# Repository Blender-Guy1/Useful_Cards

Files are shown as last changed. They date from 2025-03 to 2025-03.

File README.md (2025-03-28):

# Useful_Cards
This is a repository that contains cards that are useful or fun. This includes business cards that can play Pong and cards that act as simple electronics equipment for troubleshooting on the road.

## The Different Cards

### Business Card that Plays [Pong](https://en.wikipedia.org/wiki/Pong)
This went through 3 iterations before I got one that work, and 5 before I felt comfortable showing this to other people. It is a business card PCB that runs on a button cell battery and can play a any games that will run on the microcontroller. All of which is controlled with an [STM32L010F4](https://www.digikey.com/en/products/detail/stmicroelectronics/STM32L010F4P6/10063389) (which isn't exactly necessary for this application as I am running it like any other STM32 microcontroller.). More information can be found in the readme.md in the folder named "Business Card".

<p align="center">
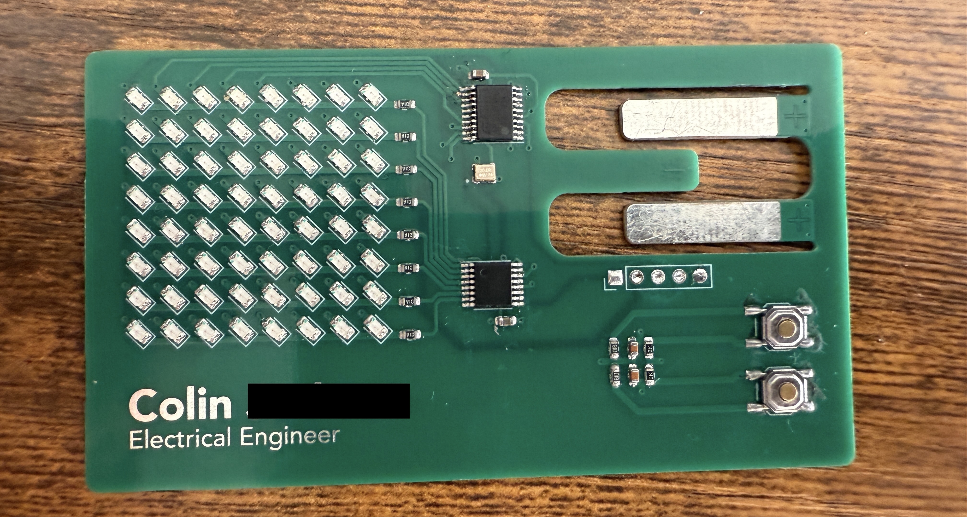
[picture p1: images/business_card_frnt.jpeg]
A picture of a green business card sized PCB that has an 8x8 display along with 2 buttons and 2 integrated circuits.
  
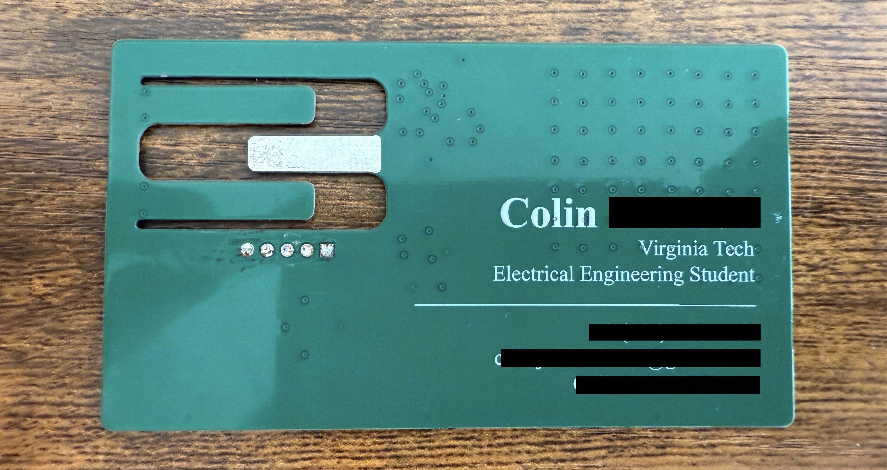
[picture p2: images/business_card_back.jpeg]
The back of the business card has text that is blurred, but it is clear it is a person's business card.
  
</p>

### Why I wanted to make Business Cards

I exhibitted at [OpenSauce 2024](https://opensauce.com/) and had the pleasure to meet [Ben Eater](https://www.youtube.com/@BenEater). He handed me a business card that was a puzzle. When a CR2025 battery was inserted, the 8 LEDs on the PCB would blink "SHAKE ME" in ASCII. Once shaken, the card wrote Ben Eater in the air. This was by far the coolest electronics idea I had ever seen. This got me thinking for a while and eventually I decided to steal his idea and make a 3D holographic business card. But that would be pretty lazy and unoriginal, so I decided on something similar that was simple. This led me to creating a business card that could play pong.

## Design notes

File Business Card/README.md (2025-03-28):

# Business Card that Plays Pong
I wanted a business card that stood out. This went through 3 iterations before I got one that work, and 5 before I felt comfortable showing this to other people. It is a business card PCB that runs on a CR2032/2025 battery and utilizes a shift register to multiplex an 8x8 LED array. All of which is controlled with an STM32L010F4 (which isn't exactly necessary for this application as I am running it like any other STM32 microcontroller.).

<p align="center">
  A picture of a green business card sized PCB that has an 8x8 display along with 2 buttons and 2 integrated circuits.
  The back of the business card has text that is blurred, but it is clear it is a person's business card.
</p>

## How it was made

### Designed in KiCAD
I designed this in KiCAD over 5 iterations (one of the iterations only had a misplaced via). I wanted to use the ATMega328p microcontroller at first because it was the only microcontroller I had ever programmed. But after running into some simple and solveable issues, I realized this project was already going to take a while, so I might as well learn something new. This is why I decided to use the [STM32L010F4](https://www.st.com/en/microcontrollers-microprocessors/stm32l010f4.html) microcontroller for its "low power" utilities. I didn't end up using an of these low power utilities because the card ended up running fine on the button cell battery and the LEDs would end up being the majority of the current draw at any one moment.
<p align="center">
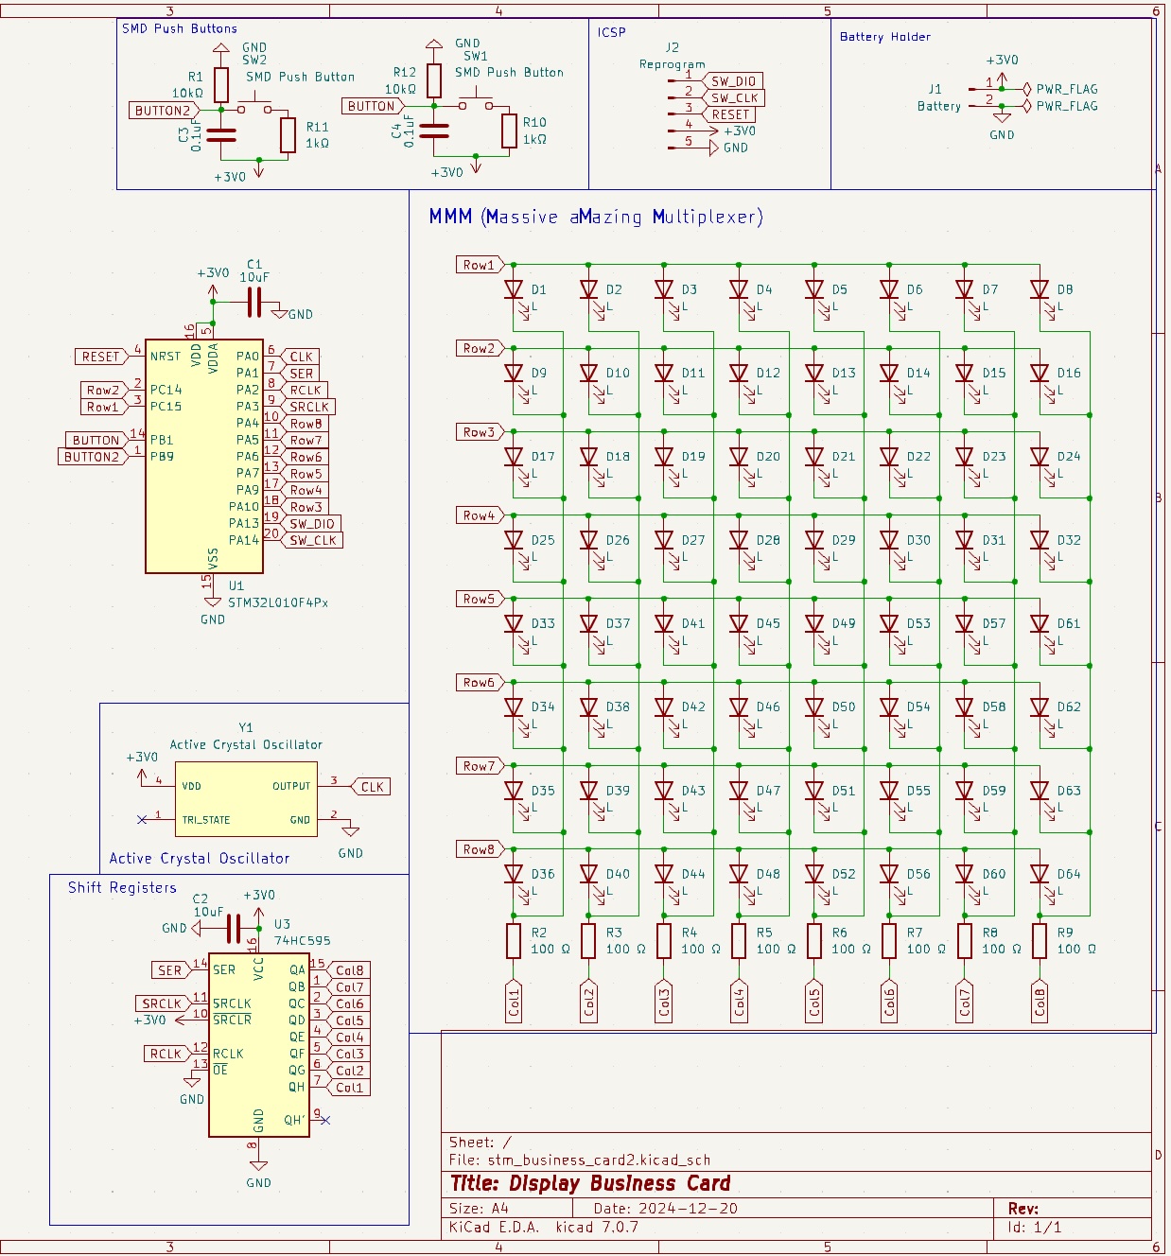
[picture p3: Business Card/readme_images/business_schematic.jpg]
A screenshot of the schematic for the business card PCB. The image includes symbols for a shift register, microcontroller, 2 buttons, some resistors and capacitors, pin headers, an active oscillator, and 64 LEDs in an array.
  
</p>

Please don't judge my PCB design skills, I am (mostly) self-taught and this circuit does not require any high frequency or high voltage wiring techniques. Feel free to try and remake this PCB so that it looks and runs nicer. I ordered the PCB from JLCPCB because no other PCB manufacturer comes close to their extremely low pricing ($4 for 5 PCBs, including shipping).
<p align="center">
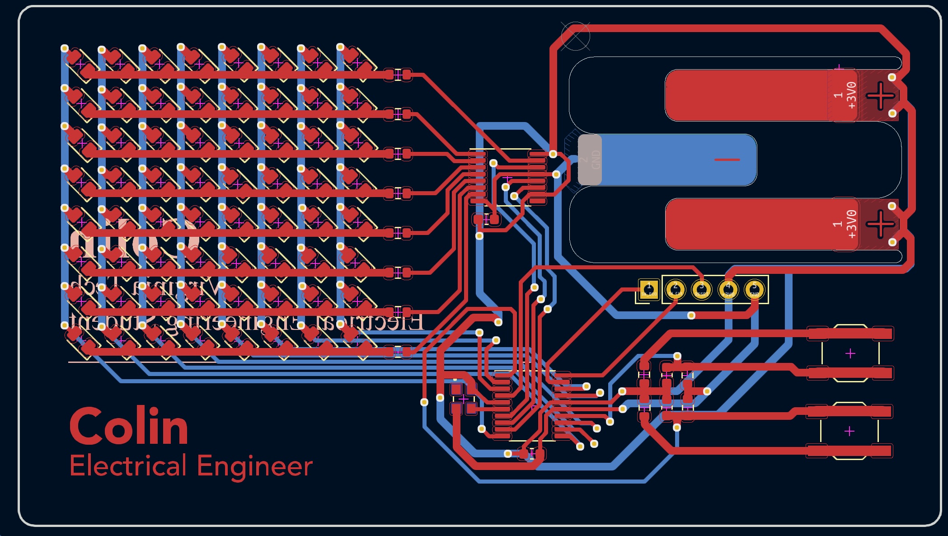
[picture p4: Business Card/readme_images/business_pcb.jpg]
A screenshot of a PCB design from KiCAD. It includes two layers
  
</p>

I then soldered all the components on using a soldering iron from ace-hardware and a hot air soldering station. Surprisngly it only took 2 hours to fully assemble. However, I did make a mistake soldering one of the ICs which led to an additional hour of debugging my code to figure out why the shift register wasn't working.

## How does it work?
This PCB contains 2 [SMD](https://en.wikipedia.org/wiki/Surface-mount_technology) buttons, a [shift register](https://learn.sparkfun.com/tutorials/shift-registers/all), a LED display, and an STM32 Microcontroller. 

The microcontroller lets the shift register know what Rows to pull HIGH. Then the microcontroller pulls the Columns it wants to turn on LOW. This is done very fast to turn on 1 pixel at a time above the frequency necessary for [Persistence of Vision](https://en.wikipedia.org/wiki/Persistence_of_vision) to take effect.

I program the microcontroller through temporary header pins, so that it reads the inputs from the buttons.

### Programming-wise:
The microcontroller is programmed in C.
There is an 8x8 array that is fed to a function that runs all of the display actions like communicating with the shift register and pulling the columns HIGH/LOW. I can change that array in between the display function calls. I made a simple program that plays pong.

To make things easier to program in the future, I made a really bad simulator to simulate the C code before I upload it so that I don't have to upload it to test every time. The simulator runs the same C code from the microcontroller (minus the display function and some microcontroller-specific code) and then prints the array to a CSV file. The CSV file is then read by a python program (I know, it's pretty bad, but I didn't get into electronics to program) which runs PyGame (I KNOW, THERE ARE BETTER OPTIONS) and displays 64 rectangles in an array simulating the PCB. 
The only differences between programming the PCB and the simulator is that the timer code calls a different function, but acts very similar.

## Q&A

### Why shift registers?
I chose shift registers because I honestly didn't know what decoders were. One reason I might use shift registers again for future cards is if I need to multiplex a large enough amount of LEDs that it would be necessary to flash a row at a time instead of individual pixels.

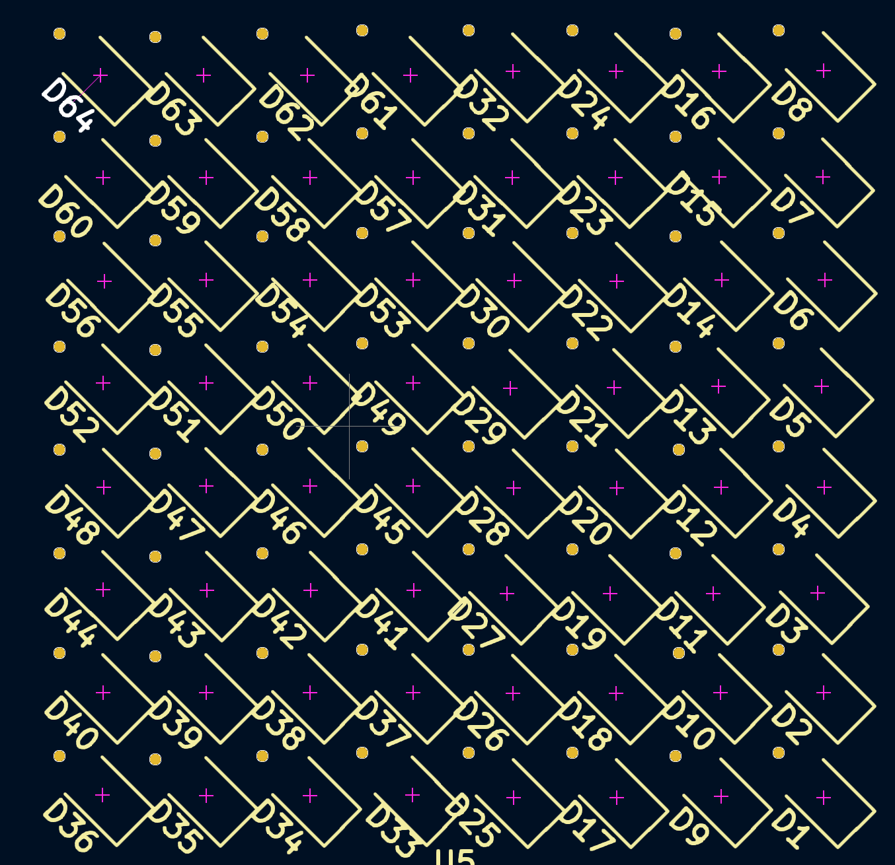
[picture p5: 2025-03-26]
Circle Card Game/stm_cardGame/Screenshot 2024-12-20 at 10.29.36 PM.png

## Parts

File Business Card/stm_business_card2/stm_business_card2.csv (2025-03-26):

Comment | Designator | Footprint | LCSC
10uF | C1,C2 | Capacitor_SMD:C_0603_1608Metric | C70225
0.1uF | C3,C4 | Capacitor_SMD:C_0603_1608Metric | C1590
L | D1,D2,D3,D4,D5,D6,D7,D8,D9,D10,D11,D12,D13,D14,D15,D16,D17,D18,D19,D20,D21,D22,D23,D24,D25,D26,D27,D28,D29,D30,D31,D32,D33,D34,D35,D36,D37,D38,D39,D40,D41,D42,D43,D44,D45,D46,D47,D48,D49,D50,D51,D52,D53,D54,D55,D56,D57,D58,D59,D60,D61,D62,D63,D64 | LED_SMD:LED_0805_2012Metric | C434431
Battery | J1 | Colin New Footprints:CR2025 Circuit Board Battery Holder
Reprogram | J2 | Connector_PinHeader_2.54mm:PinHeader_1x05_P2.54mm_Vertical
10kΩ | R1,R12 | Resistor_SMD:R_0603_1608Metric | C15401
1kΩ | R10,R11 | Resistor_SMD:R_0603_1608Metric | C14676
100 Ω | R2,R3,R4,R5,R6,R7,R8,R9 | Resistor_SMD:R_0603_1608Metric | C3017758
SMD Push Button | SW1,SW2 | Button_Switch_SMD:SW_SPST_TL3342 | C2874421
STM32L010F4Px | U1 | Package_SO:TSSOP-20_4.4x6.5mm_P0.65mm | C529415
74HC595 | U3 | Package_SO:TSSOP-16_4.4x5mm_P0.65mm | C273642
Active Crystal Oscillator | Y1 | Colin New Footprints:OSC_ECS-2520S25-250-FN-TR | C1857764

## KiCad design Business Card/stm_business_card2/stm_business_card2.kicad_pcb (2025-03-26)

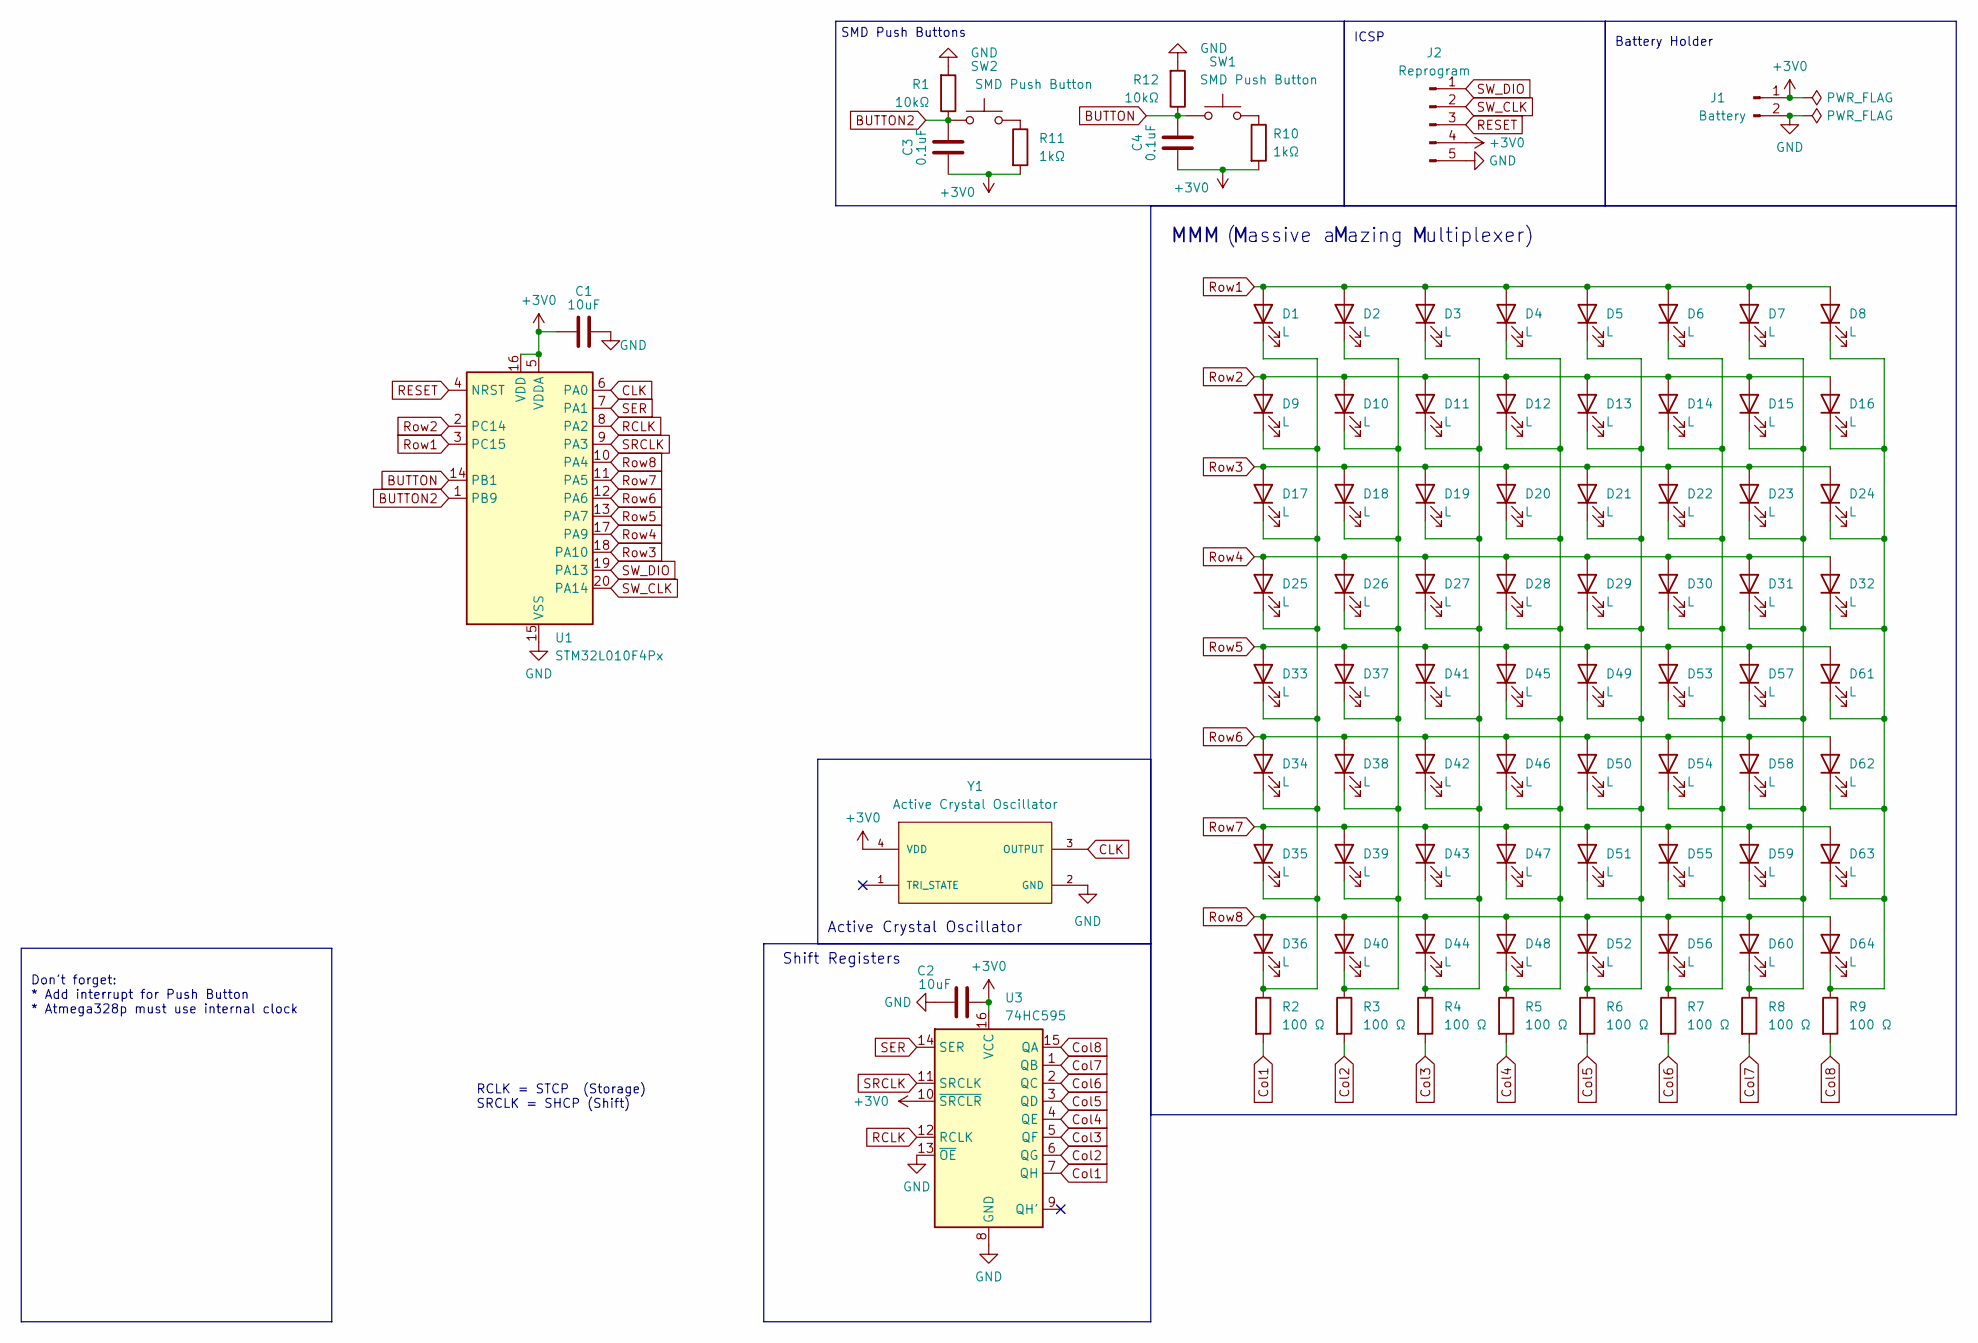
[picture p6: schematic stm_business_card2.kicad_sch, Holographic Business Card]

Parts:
C1, C2: 10uF; C_0603_1608Metric; LCSC C70225
C3, C4: 0.1uF; C_0603_1608Metric; LCSC C1590
D1, D2, D3, D4, D5, D6, D7, D8, D9, D10, D11, D12, D13, D14, D15, D16, D17, D18, D19, D20, D21, D22, D23, D24, D25, D26, D27, D28, D29, D30, D31, D32, D33, D34, D35, D36, D37, D38, D39, D40, D41, D42, D43, D44, D45, D46, D47, D48, D49, D50, D51, D52, D53, D54, D55, D56, D57, D58, D59, D60, D61, D62, D63, D64: L; LED_0805_2012Metric; LCSC C434431
J1: Battery; CR2025 Circuit Board Battery Holder
J2: Reprogram; PinHeader_1x05_P2.54mm_Vertical
R1, R12: 10kΩ; R_0603_1608Metric; LCSC C15401
R2, R3, R4, R5, R6, R7, R8, R9: 100 Ω; R_0603_1608Metric; LCSC C3017758
R10, R11: 1kΩ; R_0603_1608Metric; LCSC C14676
SW1, SW2: SMD Push Button; SW_SPST_TL3342; LCSC C2874421
U1: STM32L010F4Px; TSSOP-20_4.4x6.5mm_P0.65mm; LCSC C529415
U3: 74HC595; TSSOP-16_4.4x5mm_P0.65mm; LCSC C273642
Y1: Active Crystal Oscillator; OSC_ECS-2520S25-250-FN-TR; PARTREV 2017; LCSC C1857764

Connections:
+3V0: C1.1, C2.2, C3.1, C4.1, J1.1, J2.4, R10.2, R11.2, U1.5 (VDDA), U1.16 (VDD), U3.10 (~SRCLR), U3.16 (VCC), Y1.4 (VDD)
BUTTON: C4.2, R12.1, SW1.1, U1.14 (PB1)
BUTTON2: C3.2, R1.1, SW2.1, U1.1 (PB9)
CLK: U1.6 (PA0), Y1.3 (OUTPUT)
Col1: R2.2, U3.7 (QH)
Col2: R3.2, U3.6 (QG)
Col3: R4.2, U3.5 (QF)
Col4: R5.2, U3.4 (QE)
Col5: R6.2, U3.3 (QD)
Col6: R7.2, U3.2 (QC)
Col7: R8.2, U3.1 (QB)
Col8: R9.2, U3.15 (QA)
GND: C1.2, C2.1, J1.2, J2.5, R1.2, R12.2, U1.15 (VSS), U3.8 (GND), U3.13 (~OE), Y1.2 (GND)
unnamed: D1.1 (K), D9.1 (K), D17.1 (K), D25.1 (K), D33.1 (K), D34.1 (K), D35.1 (K), D36.1 (K), R2.1
unnamed: D2.1 (K), D10.1 (K), D18.1 (K), D26.1 (K), D37.1 (K), D38.1 (K), D39.1 (K), D40.1 (K), R3.1
unnamed: D3.1 (K), D11.1 (K), D19.1 (K), D27.1 (K), D41.1 (K), D42.1 (K), D43.1 (K), D44.1 (K), R4.1
unnamed: D4.1 (K), D12.1 (K), D20.1 (K), D28.1 (K), D45.1 (K), D46.1 (K), D47.1 (K), D48.1 (K), R5.1
unnamed: D5.1 (K), D13.1 (K), D21.1 (K), D29.1 (K), D49.1 (K), D50.1 (K), D51.1 (K), D52.1 (K), R6.1
unnamed: D6.1 (K), D14.1 (K), D22.1 (K), D30.1 (K), D53.1 (K), D54.1 (K), D55.1 (K), D56.1 (K), R7.1
unnamed: D7.1 (K), D15.1 (K), D23.1 (K), D31.1 (K), D57.1 (K), D58.1 (K), D59.1 (K), D60.1 (K), R8.1
unnamed: D8.1 (K), D16.1 (K), D24.1 (K), D32.1 (K), D61.1 (K), D62.1 (K), D63.1 (K), D64.1 (K), R9.1
unnamed: R10.1, SW1.2
unnamed: R11.1, SW2.2
RCLK: U1.8 (PA2), U3.12 (RCLK)
RESET: J2.3, U1.4 (NRST)
Row1: D1.2 (A), D2.2 (A), D3.2 (A), D4.2 (A), D5.2 (A), D6.2 (A), D7.2 (A), D8.2 (A), U1.3 (PC15)
Row2: D9.2 (A), D10.2 (A), D11.2 (A), D12.2 (A), D13.2 (A), D14.2 (A), D15.2 (A), D16.2 (A), U1.2 (PC14)
Row3: D17.2 (A), D18.2 (A), D19.2 (A), D20.2 (A), D21.2 (A), D22.2 (A), D23.2 (A), D24.2 (A), U1.18 (PA10)
Row4: D25.2 (A), D26.2 (A), D27.2 (A), D28.2 (A), D29.2 (A), D30.2 (A), D31.2 (A), D32.2 (A), U1.17 (PA9)
Row5: D33.2 (A), D37.2 (A), D41.2 (A), D45.2 (A), D49.2 (A), D53.2 (A), D57.2 (A), D61.2 (A), U1.13 (PA7)
Row6: D34.2 (A), D38.2 (A), D42.2 (A), D46.2 (A), D50.2 (A), D54.2 (A), D58.2 (A), D62.2 (A), U1.12 (PA6)
Row7: D35.2 (A), D39.2 (A), D43.2 (A), D47.2 (A), D51.2 (A), D55.2 (A), D59.2 (A), D63.2 (A), U1.11 (PA5)
Row8: D36.2 (A), D40.2 (A), D44.2 (A), D48.2 (A), D52.2 (A), D56.2 (A), D60.2 (A), D64.2 (A), U1.10 (PA4)
SER: U1.7 (PA1), U3.14 (SER)
SRCLK: U1.9 (PA3), U3.11 (SRCLK)
SW_CLK: J2.2, U1.20 (PA14)
SW_DIO: J2.1, U1.19 (PA13)

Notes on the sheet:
( assive a azing ultiplexer)
SMD Push Buttons
Don't forget: * Add interrupt for Push Button * Atmega328p must use internal clock
Shift Registers
MMM
RCLK = STCP (Storage) SRCLK = SHCP (Shift)
Battery Holder
ICSP
Active Crystal Oscillator

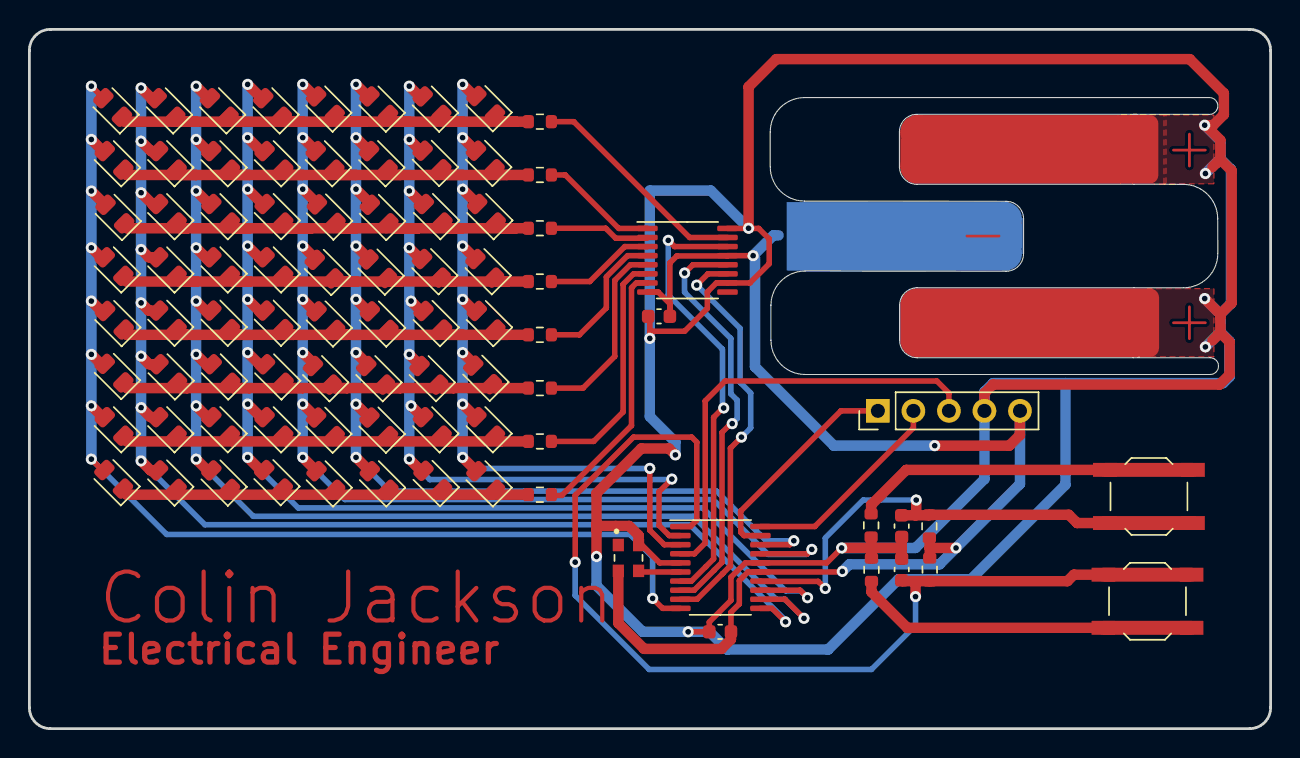
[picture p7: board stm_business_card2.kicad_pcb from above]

Board: 2 copper layers, 88.8 x 50.0 mm, 87 parts (0 on the bottom side), 37 nets.

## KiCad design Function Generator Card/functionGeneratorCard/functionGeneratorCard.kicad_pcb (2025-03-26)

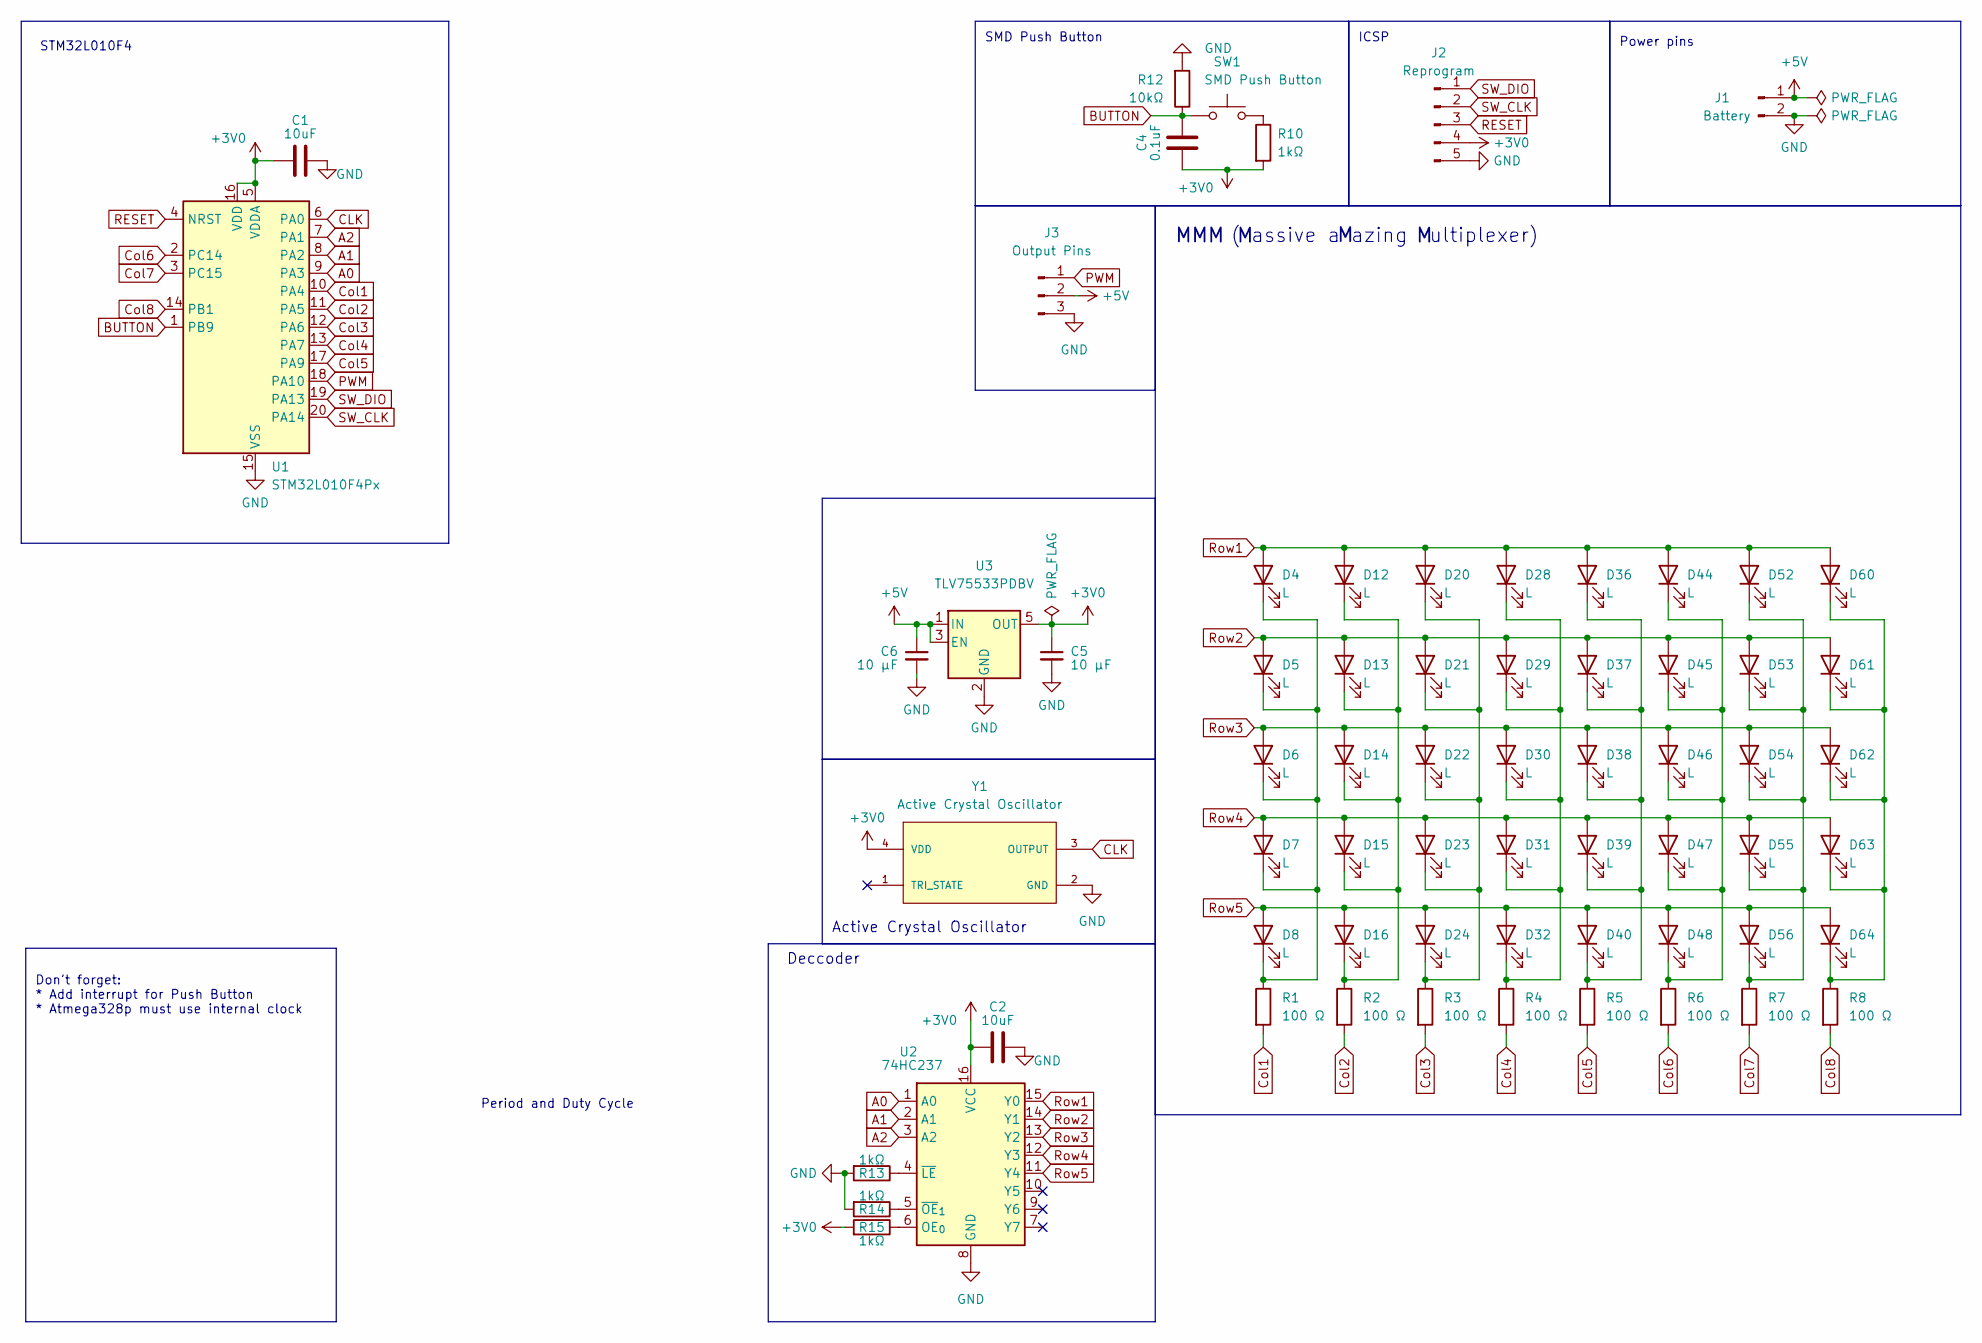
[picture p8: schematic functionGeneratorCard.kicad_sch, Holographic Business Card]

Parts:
C1, C2: 10uF; C_0603_1608Metric; LCSC C70225
C4: 0.1uF; C_0603_1608Metric; LCSC C1590
C5, C6: 10 µF; C_0603_1608Metric
D4, D5, D6, D7, D8, D12, D13, D14, D15, D16, D20, D21, D22, D23, D24, D28, D29, D30, D31, D32, D36, D37, D38, D39, D40, D44, D45, D46, D47, D48, D52, D53, D54, D55, D56, D60, D61, D62, D63, D64: L; LED_0805_2012Metric; LCSC C434431
J1: Battery; 2 Pin SMD (2.54)
J2: Reprogram; PinHeader_1x05_P2.54mm_Vertical
J3: Output Pins; 3 Pin SMD (2.54)
R1, R2, R3, R4, R5, R6, R7, R8: 100 Ω; R_0603_1608Metric; LCSC C3017758
R10, R13, R14, R15: 1kΩ; R_0603_1608Metric; LCSC C14676
R12: 10kΩ; R_0603_1608Metric; LCSC C15401
SW1: SMD Push Button; SW_SPST_TL3342; LCSC C2874421
U1: STM32L010F4Px; TSSOP-20_4.4x6.5mm_P0.65mm; LCSC C529415
U2: 74HC237; SOT-23-16 Thin
U3: TLV75533PDBV; SOT-23-5
Y1: Active Crystal Oscillator; active crystal oscillator; PARTREV 2017; LCSC C1857764

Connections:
+3V0: C1.1, C2.1, C4.1, C5.1, J2.4, R10.2, R15.2, U1.5 (VDDA), U1.16 (VDD), U2.16 (VCC), U3.5 (OUT), Y1.4 (VDD)
+5V: C6.1, J1.1, J3.2, U3.1 (IN), U3.3 (EN)
A0: U1.9 (PA3), U2.1 (A0)
A1: U1.8 (PA2), U2.2 (A1)
A2: U1.7 (PA1), U2.3 (A2)
BUTTON: C4.2, R12.1, SW1.1, U1.1 (PB9)
CLK: U1.6 (PA0), Y1.3 (OUTPUT)
Col1: R1.2, U1.10 (PA4)
Col2: R2.2, U1.11 (PA5)
Col3: R3.2, U1.12 (PA6)
Col4: R4.2, U1.13 (PA7)
Col5: R5.2, U1.17 (PA9)
Col6: R6.2, U1.2 (PC14)
Col7: R7.2, U1.3 (PC15)
Col8: R8.2, U1.14 (PB1)
GND: C1.2, C2.2, C5.2, C6.2, J1.2, J2.5, J3.3, R12.2, R13.2, R14.2, U1.15 (VSS), U2.8 (GND), U3.2 (GND), Y1.2 (GND)
unnamed: D4.1 (K), D5.1 (K), D6.1 (K), D7.1 (K), D8.1 (K), R1.1
unnamed: D12.1 (K), D13.1 (K), D14.1 (K), D15.1 (K), D16.1 (K), R2.1
unnamed: D20.1 (K), D21.1 (K), D22.1 (K), D23.1 (K), D24.1 (K), R3.1
unnamed: D28.1 (K), D29.1 (K), D30.1 (K), D31.1 (K), D32.1 (K), R4.1
unnamed: D36.1 (K), D37.1 (K), D38.1 (K), D39.1 (K), D40.1 (K), R5.1
unnamed: D44.1 (K), D45.1 (K), D46.1 (K), D47.1 (K), D48.1 (K), R6.1
unnamed: D52.1 (K), D53.1 (K), D54.1 (K), D55.1 (K), D56.1 (K), R7.1
unnamed: D60.1 (K), D61.1 (K), D62.1 (K), D63.1 (K), D64.1 (K), R8.1
unnamed: R10.1, SW1.2
unnamed: R15.1, U2.6 (OE_{0})
unnamed: R13.1, U2.4 (~LE)
unnamed: R14.1, U2.5 (~OE_{1})
PWM: J3.1, U1.18 (PA10)
RESET: J2.3, U1.4 (NRST)
Row1: D4.2 (A), D12.2 (A), D20.2 (A), D28.2 (A), D36.2 (A), D44.2 (A), D52.2 (A), D60.2 (A), U2.15 (Y0)
Row2: D5.2 (A), D13.2 (A), D21.2 (A), D29.2 (A), D37.2 (A), D45.2 (A), D53.2 (A), D61.2 (A), U2.14 (Y1)
Row3: D6.2 (A), D14.2 (A), D22.2 (A), D30.2 (A), D38.2 (A), D46.2 (A), D54.2 (A), D62.2 (A), U2.13 (Y2)
Row4: D7.2 (A), D15.2 (A), D23.2 (A), D31.2 (A), D39.2 (A), D47.2 (A), D55.2 (A), D63.2 (A), U2.12 (Y3)
Row5: D8.2 (A), D16.2 (A), D24.2 (A), D32.2 (A), D40.2 (A), D48.2 (A), D56.2 (A), D64.2 (A), U2.11 (Y4)
SW_CLK: J2.2, U1.20 (PA14)
SW_DIO: J2.1, U1.19 (PA13)

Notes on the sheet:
( assive a azing ultiplexer)
Don't forget: * Add interrupt for Push Button * Atmega328p must use internal clock
Deccoder
MMM
Period and Duty Cycle
Power pins
ICSP
Active Crystal Oscillator
STM32L010F4
SMD Push Button

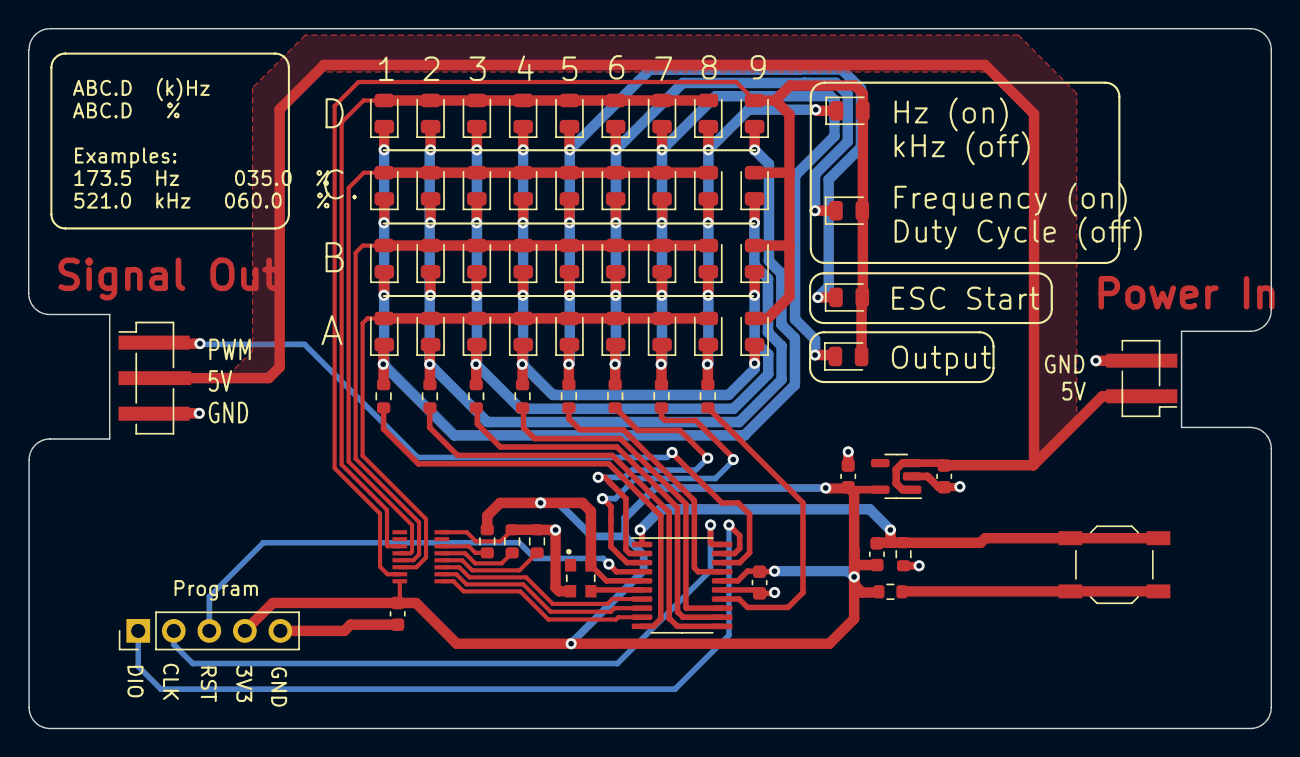
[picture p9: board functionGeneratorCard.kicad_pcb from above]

Board: 2 copper layers, 88.8 x 50.0 mm, 66 parts (0 on the bottom side), 37 nets.

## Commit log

2025-03-26 Added Files
    I added the KiCAD and Gerber files for the business card, games, and function generator.
    [functionGeneratorCard.csv, functionGeneratorCard.kicad_pcb, functionGeneratorCard.kicad_sch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]
2025-03-26 Rearranged Files and Edited ReadME
    I rearranged the files so the cards are more visible and edited the ReadME.
    [functionGeneratorCard.csv, functionGeneratorCard.kicad_pcb, functionGeneratorCard.kicad_sch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]
2025-03-26 Added to ReadMEs
    Added to the main readme and the business card readme.
    [stm_business_card2.kicad_pcb]
